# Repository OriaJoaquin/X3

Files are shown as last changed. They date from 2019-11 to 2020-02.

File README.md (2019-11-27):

Sistemas Operativos Avanzados
===============================
Proyecto de Sistemas operativos avanzados

Grupo: X3 <br /> 
-----------
* [Facal, Ernesto Manuel](https://github.com/ErnestoFacal)<br />
* [Marson, Tomás](https://github.com/tomimarson)
* [Oria, Joaquín Ariel](https://github.com/OriaJoaquin)<br /> 
* [Schiro, Andrés](https://github.com/ASchiro7)<br /> 

Proyecto: BrillaMe :star: <br /> 
---------
## Descripción

BrillaMe es un robot de clasificación de objetos. Basados en la toma de varias muestras de luz, en distintas intensidades y desde distintas posiciones, que luego seran procesadas podemos determinar si un objeto es ***brillante*** o ***no brillante***.
## Materiales

* Arduino uno 

imagenArduino

El Arduino Uno es una placa de microcontrolador de código abierto basado en el microchip ATmega328P. La placa está equipada con conjuntos de pines de E/S digitales y analógicas que pueden conectarse a varias placas de expansión y otros circuitos. La placa tiene 14 pines digitales, 6 pines analógicos y programables con el Arduino IDE (Entorno de desarrollo integrado) a través de un cable USB tipo B.Puede ser alimentado por el cable USB o por una batería externa de 9 voltios, aunque acepta voltajes entre 7 y 20 voltios.

* Modulo detector sensor de obstaculos infrarrojo arduino 

ImagenSensor01

Este módulo está conformado por un LED emisor infrarrojo y un fotodiodo el cual es sensible a la intensidad. El haz infrarrojo emitido al ser reflejado por el obstáculo es detectado por el fotodiodo, la señal del fotodiodo es comparada por el LM393 con la referencia del potenciómetro. La distancia de detección es configura con el potenciómetro. La salida del módulo es digital
Posee 2 leds, uno de los cuales indica que el módulo está alimentado y el otro enciende cuando el sensor detecta un obstáculo (muy útil para realizar el ajuste).

* Servomotor Mg996 Digital 10Kg-13Kg Torque

ImagenServo01

Este servo de rotación continua convierte a un Servo estandar RC de pulsos PWM en un Servo de velocidad de rotación continua (360°), con un Torque de 5.5Kg/cm.
El punto de reposo por defecto es de 1.5ms, pero esto se puede modificar con un pequeño destornillador de punta plana para girar un pequeño ajuste que se encuentra a la mitad del Servo.
Aplicando un ancho de pulso por encima del punto de reposo, provocara un giro en sentido inverso a las manecillas del reloj y la velocidad aumenta a medida que se aumenta el ancho de pulso. 
Aplicando un ancho de pulso por debajo del punto de reposo, provocara la rotación en sentido a las manecillas del reloj con una velocidad cada vez mayor a medida que se disminuye la anchura de pulso.

* Celda de Carga

ImagenSensorPeso

Sensor de peso o fuerza de 10 kg. El Sensor de Peso o Fuerza de 10kg es un sensor de celda de carga, que puede medir hasta poco más de 10 kg de peso, convirtiendo dicha variable de fuerza en una señal eléctrica, gracias a su confiabilidad es ampliamente utilizado en proyectos de medición de peso y básculas. Un sensor de celda de carga se encarga de convertir una fuerza o peso en una señal de voltaje, así que el peso que ejerza el objeto corresponderá a una cantidad de voltaje determinada.

* Transmisor de Cela de Carga

ImagenTransmisorCelda

Este módulo es una interface entre las celdas de carga y el microcontrolador, permitiendo poder leer el peso de manera sencilla. Internamente se encarga de la lectura del puente wheatstone formado por la celda de carga, convirtiendo la lectura analógica a digital con su conversor A/D interno de 24 bits.
Es muy utilizado en procesos industriales, sistemas de medición automatizada e industria médica.
Se comunica con el microcontrolador mediante 2 pines (Clock y Data) de forma serial.

* Módulo Bluetooth

ImagenModuloBluetooth

Permite añadir a Arduino la función de poder comunicarse sin cables con otros dispositivos mediante la tecnología Bluetooth.

* Tira de LEDs blancos.

ImagenLED

Iluminarán el objeto para luego analizar cuanta luz refleja.

## Diagrama físico

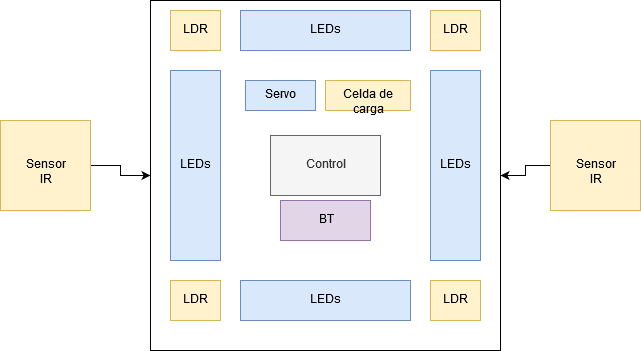
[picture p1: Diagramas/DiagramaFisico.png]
diagramaFisico


## Diagrama funcional

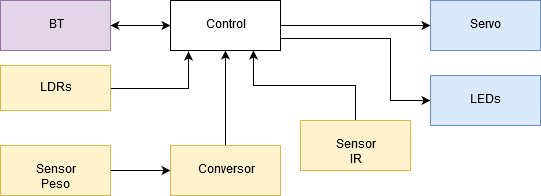
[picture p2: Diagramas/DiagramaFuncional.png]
diagramaFuncional


## Diagrama lógico

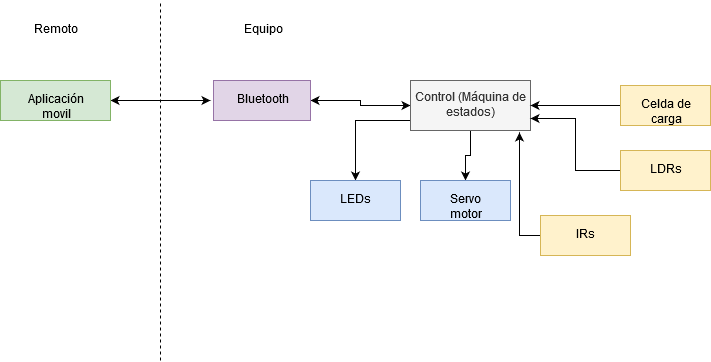
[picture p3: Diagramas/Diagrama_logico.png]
diagramaLogico


## Diagrama de software

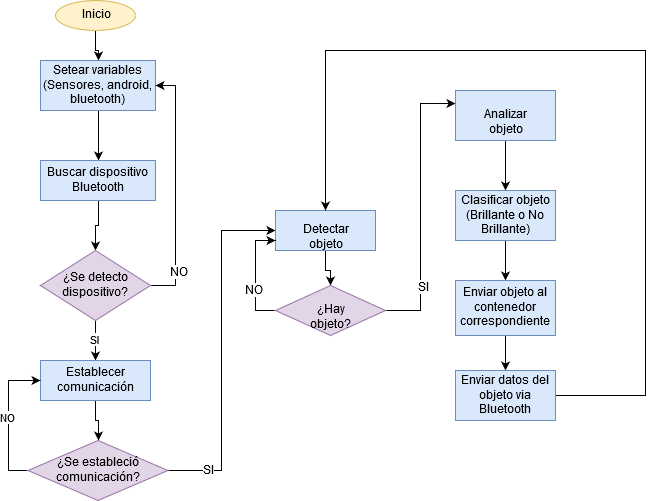
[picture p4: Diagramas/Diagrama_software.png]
diagramaSoftware


## Diagrama de ciruitos

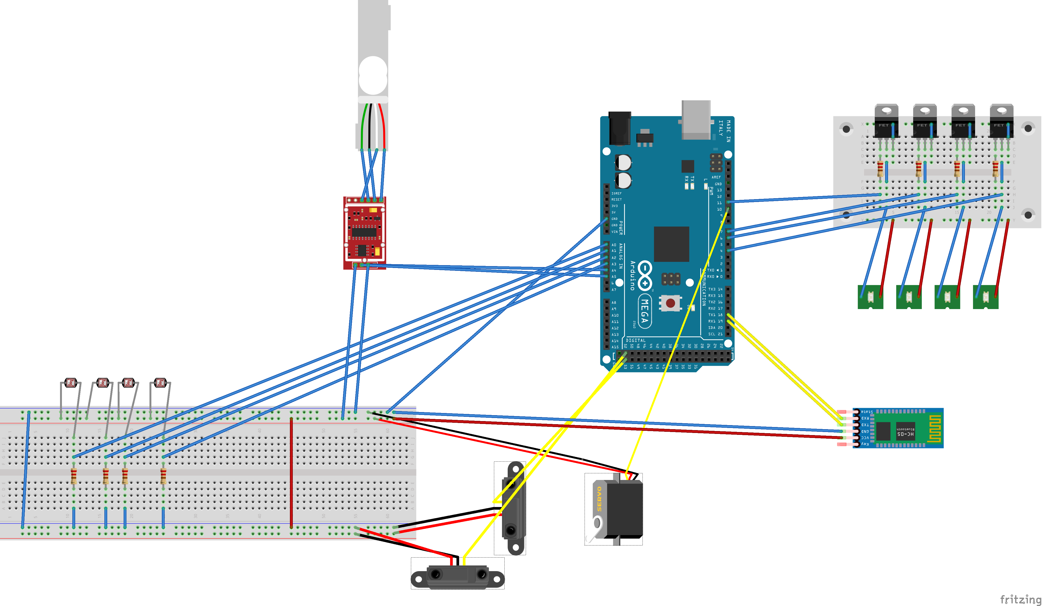
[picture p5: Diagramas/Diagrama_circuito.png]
diagramaCircuitos


## Manual de usuario 
Primeros pasos: 
 
1) Conexión Android-BrillaMe 
   - El usuario descargará, instalará, e ingresará a la aplicación de BrillaMe en su dispositivo android (*). 
   - Deberá ingresar a la opción “Buscar Dispositivos”.
   - Asegurarse de haber encendido el BT mediante la opción On.
   - Visualizar vinculados mediante la opción “Ver Vinculados.
   - Seleccionar el dispositivo BrillaMe.
 
(*) Versión mínima de android : android 4.0, (Icream Sandwich)
 
### Eventos 
 
1. Habilitar el modo detección de objeto 
   - Desde el menú principal de BrillaMe , el usuario deberá presionar el botón “Analizar Objeto” para ingresar a dicha ventana.
   - Luego de esto deberá darle a la opción “Comenzar”.
   - Activando esta opción, el usuario deberá colocar un objeto dentro de la caja.
   - Luego de detectar la celda de carga una variación en el peso, comenzará el algoritmo de análisis de objeto brillante.
   - Una vez definido si el objeto es o no brillante, la caja se inclinara en base a la señal que se le envie al servo hacia un lado o al otro ( brillante o no ) dejando caer al objeto en su respectivo recipiente.
   - Luego de esto se podrá repetir el proceso nuevamente ( hasta que alguno de los 2 recipientes se determine lleno en base a los infrarrojos).
 
2. Visualización de estadísticas 
   - Desde el menú principal de BrillaMe, el usuario podrá ver las estadísticas que fueron recolectadas a lo largo del uso de la aplicación apretando el botón “Estadísticas”, las cuales serán: 
 
     - Cesto: Indica si dicho cesto esta lleno o no. 
     - Peso: El peso total que posee el recipiente.
     - Cantidad de elementos: Cantidad de elementos que posee dicho cesto.
(*) Estos 3 valores se indicaran tanto para el cesto de objetos brillantes, como el de objetos no brillantes.
3. Acceder al Disco Mode
   - Desde el menú principal de BrillaMe, acceder a la opción Disco Mode.
   - Luego de esto agitar 2 veces el dispositivo Android para de esta manera activar el Disco Mode.

4. Prender/apagar Luces
   - Desde el menú principal de BrillaMe, acceder a la opción de “Prender/Apagar Luces”, luego de esto tapar el sensor de proximidad del celular, el cual se encuentra en la zona superior frontal al dispositivo (cerca de la cámara frontal).
   - Luego de esto, se encenderán los leds siempre y cuando dicha zona quede tapada.

5. Mover caja
   - Desde el menú principal de BrillaMe, acceder a la opción de “Mover Caja”.
   - Luego de esto orientar el dispositivo hacia un lado u otro para de esta manera hacer girar la caja hacia el respectivo lado que estemos girando el dispositivo.

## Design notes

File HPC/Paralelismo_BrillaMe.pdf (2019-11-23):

## Procesamiento HPC en Sistema de Reciclaje inteligente

Facal Ernesto
Oria Joaquín Ariel
Marsón Tomás
Schiro Andrés

Universidad Nacional de La Matanza, Departamento de Ingeniería e Investigaciones Tecnológicas, Florencio Varela 1903 - San Justo, Argentina

Resumen. El objetivo de esta investigación se basa en el análisis,

### manipulación y reconocimiento de imágenes para un sistema reciclador de basura integrado. Se utiliza un algoritmo para la detección de formas de imágenes haciendo uso de la Distancia de Hausdorff y se presenta una implementación en forma

paralela utilizando OpenMP.

### Palabras claves: OpenMP, Paralelismo, Hausdorff

Introducción

La investigación que se desarrolla en este documento está aplicada a un Sistema de reciclaje de materiales inteligente integrado. Este sistema cuenta con una cámara que monitorea el recipiente donde se colocan los materiales, dicha cámara proveerá al sistema las imágenes a procesar. Una vez identificado el material el sistema procederá a ubicar el material en el contenedor indicado según su clasificación.

Para solucionar el problema de reconocimiento de imágenes o de elementos en una imagen de forma eficiente se propone utilizar la Distancia de Hausdorff.

Este concepto mide el nivel de discrepancia entre dos grupos de puntos de un mismo espacio métrico. Este algoritmo propuesto ofrece la posibilidad de paralelizar la parte más pesada de la computación.

Dado que para obtener una aproximación fiable acerca del tipo de material debemos compararlo con un número considerable de imágenes distintas de ese tipo, va a haber un gran procesamiento de información para cada comparación antes de llegar a un resultado final. En esta etapa comienza a surgir la idea de paralelizar estas tareas.

Como herramienta de paralelización se ha decidido usar OpenMP porque ofrece una interfaz sencilla que permite realizar la paralelización introduciendo pocos cambios sobre la implementación secuencial.

Desarrollo

El sistema de reciclaje inteligente cuenta con una plataforma conectada a un sistema de volcado que utiliza servomotores para controlar los ejes de rotación y giro de la plataforma. Los residuos que son situados en la plataforma serán colocados en contenedores específicos según su clasificación. Para realizar esta clasificación el sistema contara con una cámara de manera tal que, se identifique de forma gráfica el tipo de residuo, comparando la foto del residuo colocado en la plataforma con las imágenes almacenadas en una base de datos. Los residuos podrán ser clasificados en “Papel”, “Plástico”, “Vidrio”, “Metal” o “Orgánico”. Para realizar la comparación de imágenes y obtener la clasificación del tipo de residuo utilizaremos el método de la Distancia Hausdorff. El procesamiento de la imagen será realizado por un sistema de cómputo aparte que se comunicará con la placa Arduino. La placa Arduino indica el comienzo del proceso una vez que detecta un residuo en la plataforma a través de un sensor de peso y luego recibe el resultado para finalizar la clasificación.

La idea tras la distancia Hausdorff es que puede determinarse una distancia d que indica el grado de disparidad entre conjuntos de puntos pertenecientes al mismo espacio. Si la distancia vale 0 ambos grupos serán el mismo, y cuanto mayor sea el valor, más diferentes entre sí. Esta propiedad puede usarse como base para el análisis de imágenes en formato mapa de bits, ya que, en este caso, las coordenadas de los pixeles forman los elementos del espacio y es posible comparar grupos que pertenezcan a éste. Es común aplicar la distancia de Hausdorff para obtener la medida de similitud entre dos contornos.

La definición formal de la distancia Hausdorff viene dada por la siguiente expresión matemática:

Sean A = {a1, ..., ap} y B = {b1, ..., bq} dos conjuntos finitos no vacíos, subconjuntos de un espacio métrico (M, d), se define la distancia Hausdorff dH (A, B)

dH (A, B) = max {h (A, B), h (B, A)}

Donde

h (A, B) = max min||a − b||

h (B, A) = max min||b − a||

Con a A, b B y || · || es una norma entre los puntos de A y B.

Para la paralelización de este algoritmo se utiliza OpenMP, una API ideada para la programación de tareas multiproceso con memoria compartida. La API consiste en una agrupación de directivas para el compilador, rutinas de biblioteca y variables de entorno que permiten modificar el comportamiento de la ejecución de un programa. El funcionamiento básico de OpenMP, se basa en la idea de fork-join, donde el hilo de ejecución maestro se divide en diversos hilos.

Explicación del algoritmo

La placa Arduino envía una señal al sistema de cómputo indicando que hay un residuo en la plataforma para el comienzo del procesamiento.

Parte secuencial: Se envía la foto sacada por el sistema de reciclaje al sistema de cómputo para que analice la imagen y retorne el resultado. Se enviará una foto por cada residuo ingresado.

Parte paralela: Aquí es donde se compara la imagen buscando coincidencias contra las imágenes almacenadas en la base de datos del sistema de cómputo.

Pseudocódigo

// se obtiene la imagen a procesar
Imagen = ObtenerImagen()

// se realiza la comparación (parte paralelizable) Resultado = DistanciaHausdorff(Imagen)

// se clasifica el resultado obtenido
TipoResiduo = ClasificarSegunTipoResiduo(Resultado)

// envía a la placa Arduino el tipo de residuo para que proceda a reciclarlo según corresponda
Respuesta (TipoResiduo)

A continuación, se explicará la función DistanciaHausdorff.

La función consiste en tres bucles anidados, el primer for recorre las imágenes almacenadas en la base de datos, las cuales ya se encuentran expresadas en contorno, el cual está almacenado en un vector de coordenadas. El segundo recorre los pixeles de los contornos de la imagen que se obtuvo del residuo de la plataforma y en el tercer for, para cada píxel, recorre todos los pixeles de los contornos de la primera imagen y calculara las distancias entre estos y se guardara siempre la menor. Al finalizar el recorrido para un punto dado de la primera imagen seleccionará aquella distancia que sea mayor entre la nueva y el máximo anterior. Este proceso se realiza en el sentido imagen1 → imagen2 y luego en el sentido imagen1 ← imagen2. Finalmente devolverá la imagen que tenga menos distancia con la imagen original.

DistanciaHausdorff (Imagen)

//Para cada imagen de la BD…
For( Imágenes BD[ImagenN] ){
// Para cada Pixel de la imagen Residuo For ( Imagen del Residuo[PixelN] )
// Para cada Pixel de la imagen BD… For (ImágenesBD[ImagenN[PixelN]]){ Obtener distancia mínima ()
}
Obtener distancia máxima ()
}
}
Obtener imagen más similar ();
// Retorno la imagen con menos distancia entre la original para que se clasifique posteriormente
Return imagen más similar;

Pruebas que pueden realizarse

Una de las pruebas que pueden realizarse es implementar el algoritmo con y sin el empleo de OpenMP, para así demostrar la diferencia en los tiempos de ejecución entre la versión secuencial y la optimizada paralelizable con OpenMP.

Los casos de prueba que se pueden realizar son colocando residuos en la plataforma del sistema de reciclaje, previamente habiendo cargado imágenes en la base de datos de ese material para que el sistema pueda comparar y realizar el procesamiento.

Conclusiones

Podemos ver que a través del uso de la propiedad de la distancia de Hausdorff es posible realizar un reconocimiento de patrones en imágenes y de esta forma poder identificar los distintos tipos de materiales para que luego el sistema integrado una vez ya clasificado el material lo recicle según corresponda.

Se utilizó OpenMP para ejecutar el algoritmo comparando paralelamente la imagen del objeto con las de la base de datos y así aumentar notablemente su rendimiento.

Referencias

1. OpenMP versus Threading in C/C++ (2014)
2. Measuring synchronization and cheduling overheads in openMp (2016)
3. Paralel computing using openMp (2017)
4. Comparación de Huellas Dactilares Usando la Distancia Hausdorff (2008)

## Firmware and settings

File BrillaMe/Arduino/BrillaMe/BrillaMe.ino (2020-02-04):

#include "BrillaMe.h"


void setup() 
{
  unsigned char currentMillis = millis();
  pinMode(LED1, OUTPUT);
  pinMode(LED2, OUTPUT);
  pinMode(LED3, OUTPUT);
  pinMode(LED4, OUTPUT);
  pinMode(IR_SHINY, INPUT);
  pinMode(IR_NONSHINY, INPUT);

  Serial.begin(9600);
  Serial1.begin(9600);

  flagLed1 = true;
  flagLed2 = false;
  flagLed3 = false;
  flagLed4 = false;
  finished = false;
  myservo.attach(SERVO);
  myservo.write(MIDDLE_ANGLE);
  bascule.begin(pinData, pinClk);
  bascule.set_scale(SCALE);
  bascule.tare();
  long zero_factor = bascule.read_average();
  pinMode(11, OUTPUT);
}


void loop() 
{
  if ( Serial1.available() && !BTBusy) 
  { 
    BTdata = Serial1.read();
    Serial.write( BTdata );
    
  }
  if ( Serial.available() && !BTBusy)
  {
    BTdata = Serial.read();
  }
  

  switch(BTdata)
  {
    case DANCE_MODE: 
    if(!BTBusy) 
      dance();
    break;
    
    case EXIT: 
      exits(); 
    break;
    
    case BEGIN_RECOGNIZING:
      detect_weight();
    break;

    case BEGIN_PATTERN: 
      begin_pattern();
    break;

    case MOVE_SERVO:
      move_servo();
    break;

    case CHECK_IR: 
      check_infrared();
    break;
    
    case MOVE_LEFT: 
      move_left();
    break;
    
    case MOVE_RIGHT:
      move_right();
    break;

    case MOVE_MIDDLE:
      move_middle();
    break;
    
    case EMPTY_SHINY:
      ShinyBaskFull = false;
    break;
    
    case EMPTY_NONSHINY:
      NonShinyBaskFull = false;
    break;

    case LIGHTS_ON: 
      lights_on();
    break;

    case LIGHTS_OUT: 
      lights_out();
    break;
      

    default:
      BTBusy = false;
  }
}


void readldr(int led)
{
  analogWrite(led, intensity);
  Serial.write(led);
  aveLdr1.push(analogRead(LDR1));
  aveLdr2.push(analogRead(LDR2));
  aveLdr3.push(analogRead(LDR3));
  aveLdr4.push(analogRead(LDR4));

  if (intensity >= MAX_INTENSITY)
  {
    analogWrite(led, 0);
  }
}


void dance()
{
  currentMillisLed = millis();
  if (currentMillisLed - previousMillisLed > timeToActionDance)
  {
    previousMillisLed = currentMillisLed;
    
    if(ledpin == LED1)
    {
      analogWrite(LED4,0);
      analogWrite(LED1,MAX_INTENSITY);
      ledpin = LED2;  
    }
    else if(ledpin == LED2)
    {
      analogWrite(LED1, 0);
      analogWrite(LED2,MAX_INTENSITY);
      ledpin = LED3;
    }
    
    else if(ledpin == LED3)
    {
      analogWrite(LED2, 0);
      analogWrite(LED3,MAX_INTENSITY);
      ledpin = LED4;
    }
    else
    {
      analogWrite(LED3,0);
      analogWrite(LED4,MAX_INTENSITY);
      ledpin = LED1;
    }
  }
}


void begin_pattern()
{ 
  currentMillisLed = millis();
  if (currentMillisLed - previousMillisLed > timeToActionLed)
  {
    previousMillisLed = currentMillisLed;    
    intensity += INTENSITY_VALUE;
    readldr(ledpin);
    if(intensity >= MAX_INTENSITY)
    {
      Serial.println("");
      Serial.println("");
      Serial.print("///////////LED ");
      Serial.print(lednumber +1);
      Serial.println(":    ");
      Serial.print("Media LDR1   ");    
      Serial.println(aveLdr1.mean());
      Serial.print("Media LDR2   ");
      Serial.println(aveLdr2.mean());
      Serial.print("Media LDR3   ");
      Serial.println(aveLdr3.mean());
      Serial.print("Media LDR4   ");
      Serial.println(aveLdr4.mean());
  
      Serial.print("Desvio LDR1   "); 
      Serial.println(aveLdr1.stddev());
      Serial.print("Desvio LDR2   "); 
      Serial.println(aveLdr2.stddev());
      Serial.print("Desvio LDR3   "); 
      Serial.println(aveLdr3.stddev());
      Serial.print("Desvio LDR4   "); 
      Serial.println(aveLdr4.stddev());
  
      aveLed.push(aveLdr1.stddev());
      aveLed.push(aveLdr2.stddev());
      aveLed.push(aveLdr3.stddev());
      aveLed.push(aveLdr4.stddev());
      lednumber++;
      intensity = 0;
      if(ledpin == LED1)
        ledpin = LED2;
      else if(ledpin == LED2)
        ledpin = LED3;
      else if(ledpin == LED3)
        ledpin = LED4;
      else
      {
        finished = true;
        BTdata = MOVE_SERVO;
        intensity = 0;
        lednumber = 0;
        ledpin = LED1;  
      }
    
      if(finished)
      {
        Serial.println("------ TOTAL ------ ");
        Serial.print("Media de desvio: ");
        Serial.println(aveLed.mean());
       if(aveLed.mean() > MIN_SHINY_DEVIATION)
         isShiny = true;
       else
         isShiny = false;
       BTdata = MOVE_SERVO;
      }
          
      aveLed.clear();
      aveLdr1.clear();
      aveLdr2.clear();
      aveLdr3.clear();
      aveLdr4.clear();
    }
  }
}

void move_servo()
{
  currentMillisServo = millis();
  if(currentMillisServo - previousMillisServo > timeToActionServo)
  {
    previousMillisServo = currentMillisServo;
    if(isShiny)
    {
      Serial.println("Es brillante");
      angle++;
      Serial.println(angle);
      if(angle < TOP_ANGLE)                                  
      {
         myservo.write(angle);
         delay(10);
      }
      else
      {
        waiting_drop++;
        if(waiting_drop == 200)
        {
          myservo.write(MIDDLE_ANGLE);
          angle = MIDDLE_ANGLE;
          BTdata = CHECK_IR;
          waiting_drop = 0;
        }
      }   
    }
    else
    {
      Serial.println("Es No Brillante");
       angle--;
       if(angle > BOTTOM_ANGLE) 
       {                                
         myservo.write(angle);                      
       }
       else
       {
        waiting_drop++;
        if(waiting_drop == 200)
        {
          myservo.write(MIDDLE_ANGLE);
          angle = MIDDLE_ANGLE;
          BTdata = CHECK_IR;
          waiting_drop = 0;
        }
       }
    }
  }
}

void detect_weight()
{
  BTBusy = true;
  currentMillisCell = millis();
  if(currentMillisCell - previousMillisCell > timeToActionCell)
  {
    previousMillisCell = currentMillisCell; 
    actCell = bascule.get_units();
    Serial.print("Leyendo: ");
    Serial.print(actCell, 3);
    Serial.print("  kgs");
    Serial.println();
    if(actCell < (prevCell + MIN_DEVIATION) && actCell > (prevCell - MIN_DEVIATION))
    {
      if (actCell > minTolerance)
      countCell++;
      if (countCell == OBJECT_DETECTED)
      {
        BTdata = BEGIN_PATTERN;
      }
    }
    else
    {
      countCell = 0;
      prevCell = actCell;
    }
  }
}

void check_infrared()
{
  currentMillisInfrared = millis();
  if(currentMillisInfrared - previousMillisInfrared > timeToActionInfrared)
  {
    previousMillisInfrared = currentMillisInfrared;
    detectIR = false;
    isCellCharged = false;
    BTBusy = false;
    flagLed1 = true;
    finished = false;  
    BTdata = EXIT;         
    Serial1.println(isShiny);
    Serial1.println(actCell);         
    if(isShiny)
    {
      if(digitalRead(IR_SHINY) == HIGH)
        Serial1.println('1');
      else
        Serial1.println('0');    
    }
    else
    {
      if(digitalRead(IR_NONSHINY) == HIGH)
        Serial1.println('1');
      else
        Serial1.println('0'); 
    }
  } 
}

void move_left()
{
  BTBusy = true;
  currentMillisServo = millis();
  if(currentMillisServo - previousMillisServo > timeToActionServo)
  {
    angle++;
    previousMillisServo = currentMillisServo;
    if(angle < TOP_ANGLE)                                  
    {
      Serial.println(angle);
      myservo.write(angle);
      delay(0);
    }
    else  
    {
      BTBusy = false;
      BTdata = 0;
      servo_pos = 'l';
    }
  }
}

void move_right()
{
  BTBusy = true;
  currentMillisServo = millis();
  if(currentMillisServo - previousMillisServo > timeToActionServo)
  {
    previousMillisServo  = currentMillisServo;
    angle--;
    Serial.println(angle);
    if(angle > BOTTOM_ANGLE)                                  
    {
       myservo.write(angle);
       delay(0);
    }
    else
    {
      BTBusy = false;
      BTdata = 0;
      servo_pos = 'r';
    }
  }
}

void move_middle()
{
  BTBusy = true;
  currentMillisServo = millis();
  if(currentMillisServo - previousMillisServo > timeToActionServo)
  {
    previousMillisServo  = currentMillisServo;
    if(servo_pos == 'l')
      angle--;
    else
      angle++;
    if(angle != MIDDLE_ANGLE)                                  
    {
       myservo.write(angle);
       delay(0);
    }
    else
    {
      BTBusy = false;
      BTdata = 0;
      servo_pos = 'c';
    }
  }
}

void lights_on()
{
  analogWrite(LED1,MAX_INTENSITY);
  analogWrite(LED2,MAX_INTENSITY);
  analogWrite(LED3,MAX_INTENSITY);
  analogWrite(LED4,MAX_INTENSITY);
}

void lights_out()
{
  analogWrite(LED1,0);
  analogWrite(LED2,0);
  analogWrite(LED3,0);
  analogWrite(LED4,0);
}

void exits()
{
  if(!BTBusy)
  {
    analogWrite(LED1,0);
    analogWrite(LED2,0);
    analogWrite(LED3,0);
    analogWrite(LED4,0);
  }
}

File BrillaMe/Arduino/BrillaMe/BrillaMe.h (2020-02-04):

#ifndef BrillaMe_h
#define BrillaMe_h
 
#include "Arduino.h"
#include <Servo.h>
#include <Average.h>
#include "HX711.h"
#include "String.h"


const char EXIT = '0'; 
const char BEGIN_RECOGNIZING = '1';
const char DANCE_MODE = '2';
const char LIGHTS_ON = '3';
const char LIGHTS_OUT = '4';
const char EMPTY_SHINY = '5';
const char EMPTY_NONSHINY = '6';
const char BEGIN_PATTERN = '7';
const char MOVE_SERVO = '8';
const char CHECK_IR = '9';
const char MOVE_LEFT = 'A';
const char MOVE_RIGHT = 'B';
const char MOVE_MIDDLE = 'C';

#define SCALE 145000
#define MIN_DEVIATION 0.01
#define OBJECT_DETECTED 20
#define MIDDLE_ANGLE 86//94
#define BOTTOM_ANGLE 65
#define TOP_ANGLE 115
#define MAX_INTENSITY 255
#define MIN_SHINY_DEVIATION 70
#define LED1 6 
#define LED2 4 
#define LED3 7 
#define LED4 11
#define LDR1 A0 
#define LDR2 A1 
#define LDR3 A2 
#define LDR4 A3
#define SERVO 10
#define IR_SHINY 8
#define IR_NONSHINY 9

void dance();
void readldr(int);
void begin_pattern();
void move_servo();
void move_left();
void move_right();
void lights_on();
void lights_out();
void exits();
void move_middle();

int pinData = A4;
int pinClk = A5;
HX711 bascule;
Servo myservo;
int lednumber = 0, ledpin = LED1;
int angle = MIDDLE_ANGLE;
char servo_pos = 'c';
const short INTENSITY_VALUE = 4;

Average<float> aveLdr1(64);
Average<float> aveLdr2(64);
Average<float> aveLdr3(64);
Average<float> aveLdr4(64);
Average<float> aveLed(16);


boolean flagLed1, flagLed2, flagLed3, flagLed4, finished;
int intensity;
unsigned long previousMillisCell = 0, currentMillisCell = 0;
unsigned long previousMillisLed = 0 , currentMillisLed = 0;
unsigned long previousMillisServo = 0, currentMillisServo = 0;
unsigned long previousMillisInfrared = 0, currentMillisInfrared= 0;
unsigned long timeToActionServo = 5;
unsigned long timeToActionCell = 50;
unsigned long timeToActionLed = 40;
unsigned long timeToActionDance = 250;
unsigned long timeToActionInfrared = 3000;
int waiting_drop = 0;
float prevCell = 0, actCell = 0;
const float minTolerance = 0.02;
int countCell;
boolean isShiny = false, isCellCharged = false, BTBusy = false;
boolean ShinyBaskFull = false, NonShinyBaskFull = false, detectIR = false;
int BTdata = 0; 
String Output;

 
#endif

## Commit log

2019-09-11 README actualizado
    Se añadió el módulo bluetooth y el sensor de peso.
2019-09-11 README actualizado
    Se cambió imagen del módulo de bluetooth
2019-09-25 Se actualizó el README.
2019-10-19 Se crearon carpetas del proyecto. Se subio codigo de Arduino.
2019-10-19 Se comenzo con el procesamiento del las lecturas LDR
2019-10-23 Se finalizó el cálculo del promedio de la varianza
2019-10-26 Se cambiaron los tipos de datos de las variables donde se guardan las medias y las varianzas. Se refactorizó el código para que consuma menos memoria.
2019-10-26 Se sigue tratando de arreglar el problema del serial print.
    [BrillaMe.ino]
2019-10-26 Se elimino un archivo de codigo de arduino que se usaba.
2019-11-02 Se refactorizo el codigo.
2019-11-02 Se refactorizo el codigo usando la libreria average.h
2019-11-02 Se agregaron las lecturas de los LDRs que faltaban.
2019-11-02 La rutina comienza automaticamente luego de detectarse un objeto.
2019-11-09 Se cambio disposicion de las carpetas.
2019-11-09 Se agrego libreria bluetooth al proyecto. Se hizo la funcionalidad para calcular la media de los desvios.
2019-11-09 Se completó el algoritmo
2019-11-18 Se refactorizó el codigo y se creó un .h. Además se añadió el switch para cada orden del BT
2019-11-18 Se Refactorizó por segunda vez. Se agregaron los sensores IR.
2019-11-18 Se agregó el proyecto HPC
2019-11-21 Se redefineron los estados a const char, se corrijio el switch y se mejoró la comunicacion BT
2019-11-23 Se formateó a maquinas de estado y se corrigio la lógica del servo
    [BrillaMe.h, BrillaMe.ino, servo.ino]
2019-11-23 Se mejoró el pseudocodigo
2019-11-24 versión definitiva de los pines y maquina de estados
2019-11-26 Se agregó diagrama de software al README
2019-11-26 Se agregó código fuente del diagrama de software.
2019-11-27 Se agregó diagrama de circuitos.
2019-11-27 Se agregó manual de usuario.
2019-11-27 Se le dió formato al manual de usuario en el READ.MD
2019-11-27 Se agregó código fuente del diagrama de circuitos.
    [ConexionArduino.fzz]
2019-11-27 Se arreglaron nombres de variables. Se configuraron los nuevos valores para el servo.
    [BrillaMe.h, BrillaMe.ino, servo.ino]
2019-11-27 Se agregó el proyecto de Android a este repositorio.
2019-12-04 Versión Final (Quizás faltó modificar factor de calibración de Celda)
